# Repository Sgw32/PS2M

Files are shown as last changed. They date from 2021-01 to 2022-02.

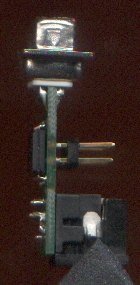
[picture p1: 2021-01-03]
original/ps2mhiiri627_files/hiir07sivusta.jpg

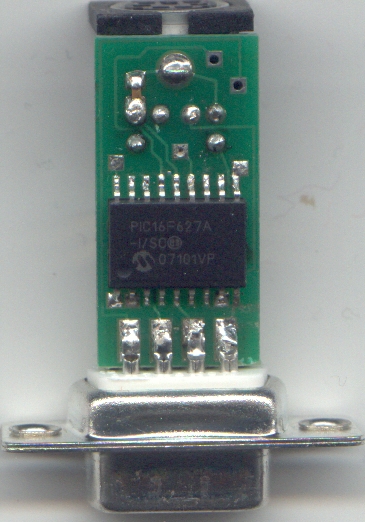
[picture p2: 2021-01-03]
original/ps2mhiiri627_files/hiir07alta.jpg

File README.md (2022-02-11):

# PS2M Amiga mouse adapter

** NEW: ATARI VERSION 

Connect your good old laser PS/2 mouse to your Amiga Retro computer with this cheap and reliable adapter(and forget about non-usable old Amiga mouse)

Features: 

1) PS2M firmware with doubled pins for super reliability of PIC MCU

2) Can be edited to work with Atari

3) Plug&play solution

4) Works with all known Amiga author has

Good resolution, high precision.

Truly 100% open source solution, all hw and sw files available. 

Firmware by Denis Sotchenko's PS2M mouse adapter

PCB by mkl211015 (a little bit adopted to modern PCB software by me)

Flashing using TL866 programmer(see source code)

License:

GNU GPL Version 2 (see gpl.txt)

Original information: http://www.mklboards.fi/ps2mhiiri627/

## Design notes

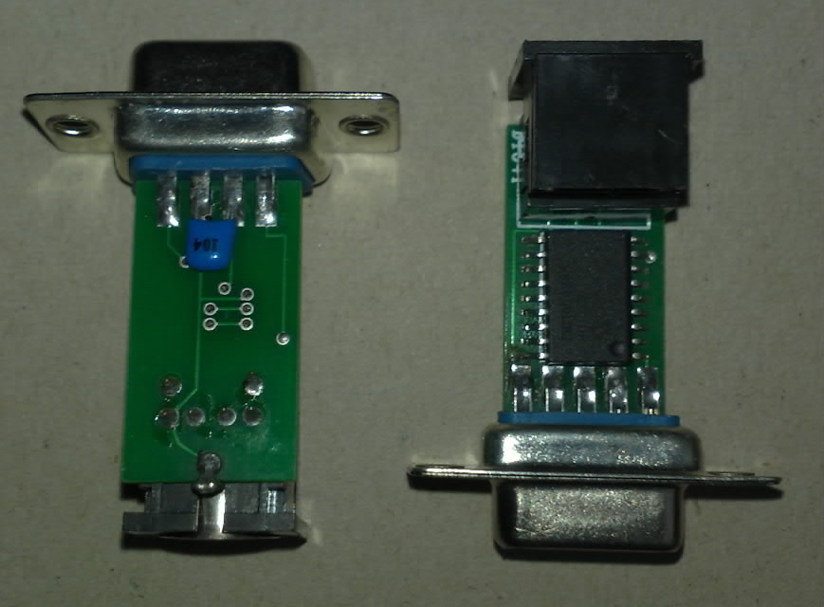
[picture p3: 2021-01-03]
original/ps2mhiiri627_files/hiir08.jpg

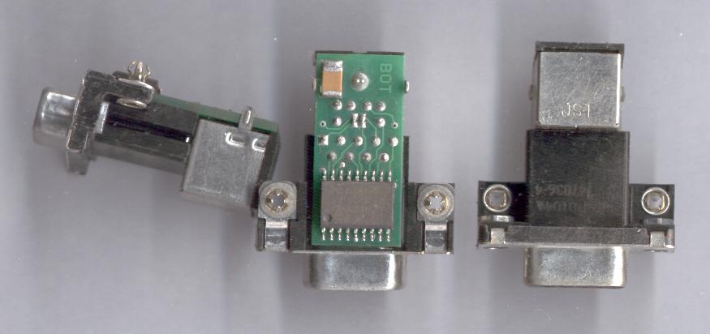
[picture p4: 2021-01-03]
original/ps2mhiiri627_files/hiir21.jpg

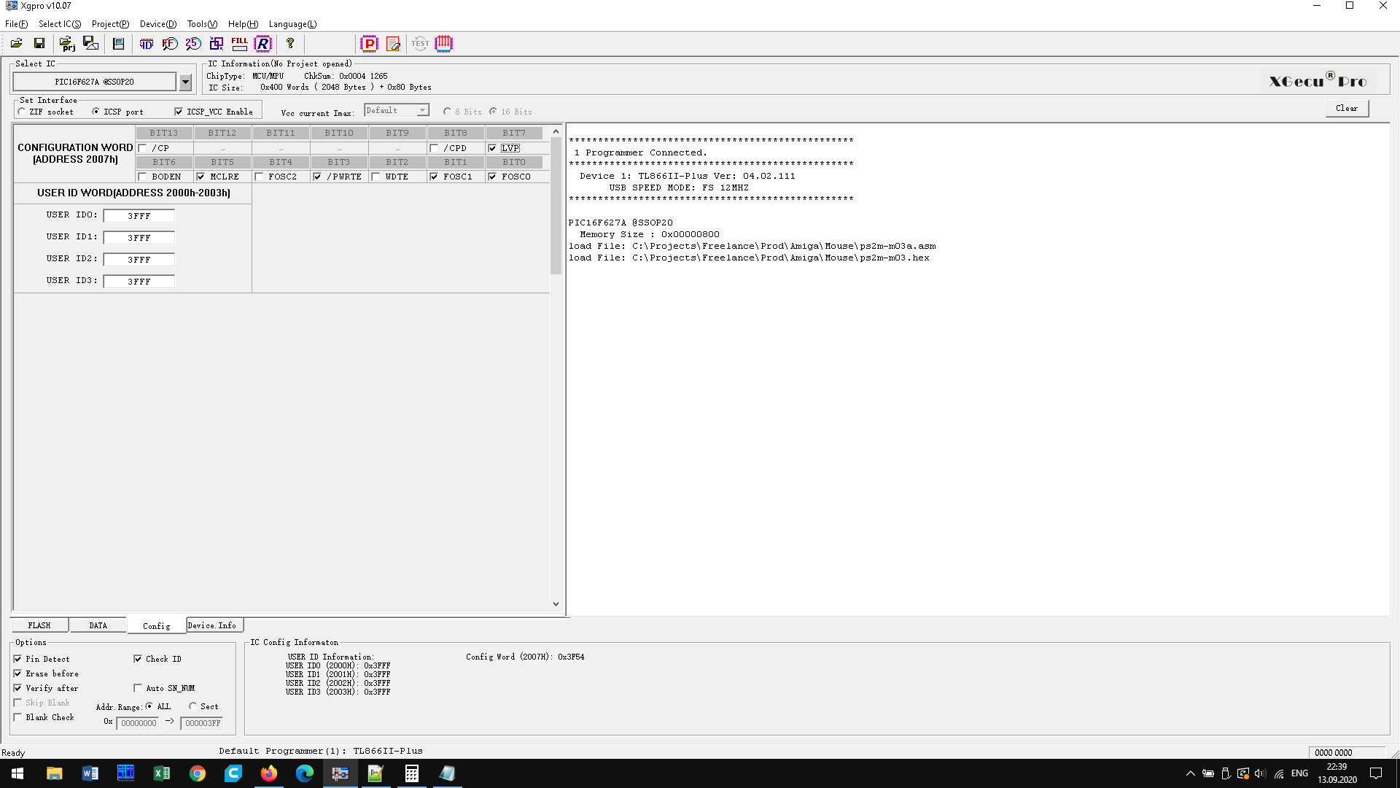
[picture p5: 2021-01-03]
gpasm_ps2m_atari/ps2m_fuse.png

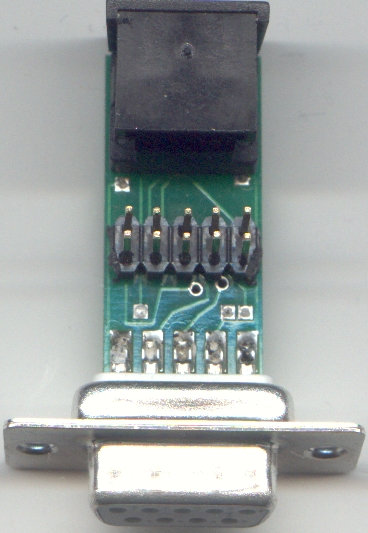
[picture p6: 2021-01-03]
original/ps2mhiiri627_files/hiir07.jpg

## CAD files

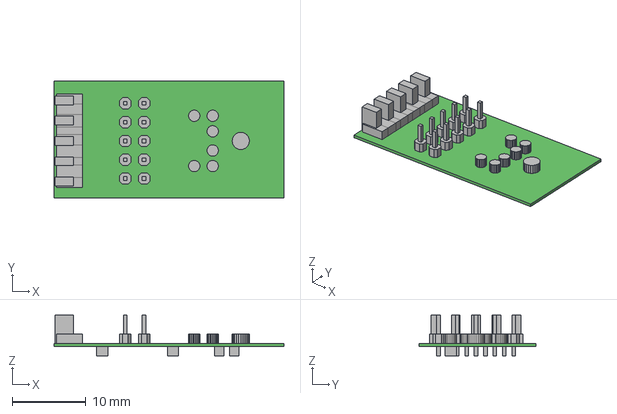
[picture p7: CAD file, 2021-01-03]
hiiri627v07.step
31.1 x 15.9 x 5.49 mm
Extruded x 61

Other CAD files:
hiiri627v07.DWG
hiiri627v07.DXF

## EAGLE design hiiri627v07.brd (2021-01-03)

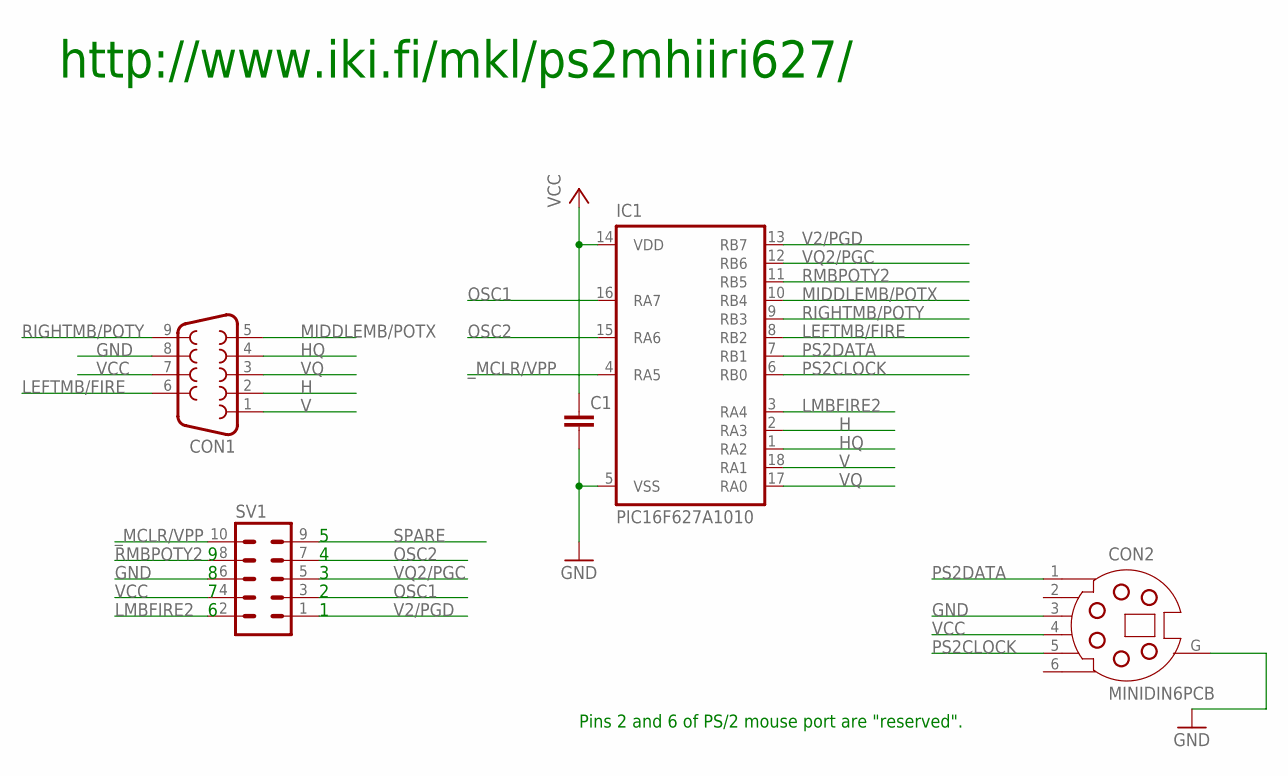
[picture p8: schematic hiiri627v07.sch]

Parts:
C1: C-EUC0805K; C0805K
CON1: F09D
CON2: MINIDIN6PCB
IC1: PIC16F627A1010; SO18-10101020
SV1: ML10

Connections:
GND: C1.2, CON1.8, CON2.3, CON2.G, IC1.5 (VSS), SV1.6
H: CON1.2, IC1.2 (RA3)
HQ: CON1.4, IC1.1 (RA2)
LEFTMB/FIRE: CON1.6, IC1.8 (RB2)
LMBFIRE2: IC1.3 (RA4), SV1.2
MIDDLEMB/POTX: CON1.5, IC1.10 (RB4)
OSC1: IC1.16 (RA7), SV1.3
OSC2: IC1.15 (RA6), SV1.7
PS2CLOCK: CON2.5, IC1.6 (RB0)
PS2DATA: CON2.1, IC1.7 (RB1)
RIGHTMB/POTY: CON1.9, IC1.9 (RB3)
RMBPOTY2: IC1.11 (RB5), SV1.8
SPARE: SV1.9
V: CON1.1, IC1.18 (RA1)
V2/PGD: IC1.13 (RB7), SV1.1
VCC: C1.1, CON1.7, CON2.4, IC1.14 (VDD), SV1.4
VQ: CON1.3, IC1.17 (RA0)
VQ2/PGC: IC1.12 (RB6), SV1.5
_MCLR/VPP: IC1.4 (RA5), SV1.10

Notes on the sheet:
Pins 2 and 6 of PS/2 mouse port are "reserved".
http://www.iki.fi/mkl/ps2mhiiri627/

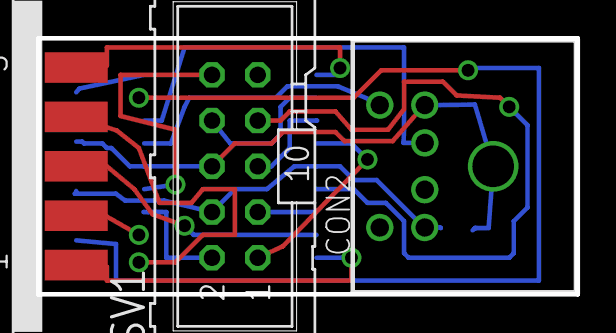
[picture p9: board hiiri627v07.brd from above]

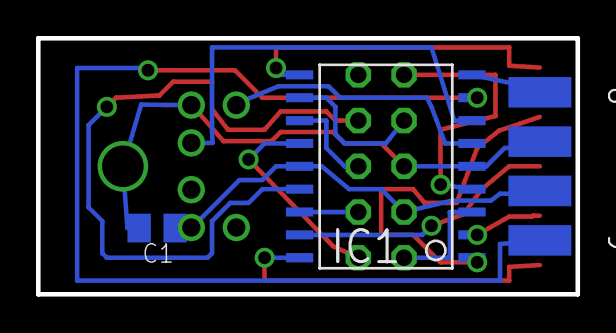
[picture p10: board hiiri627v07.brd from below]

Board: 2 copper layers, 30.0 x 14.2 mm, 5 parts (2 on the bottom side), 18 nets.

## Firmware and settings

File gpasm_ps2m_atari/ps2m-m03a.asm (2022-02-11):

;; mkl modifications to original "ps2m" v1.5 code
;; VER: 1.5.03 (20.03.08) ;http://www.iki.f/mkl/ps2mhiiri627/
;; Rev.A 21.03.08, only comments added, .hex file not changed
;;
;; ps2m functionality "POWER" removed for (my) reading clarity.
;; The mouse "POWER" switching feature was in some older version
;; circuits of mouse adapter, as described in ps2m docs.
;;
;; Copy the output to amiga right mouse button signal line
;; from RB3 also to RA6 and RA7, so connected together they
;; can sink more current. One A1200 didn't recognise right
;; mouse button press, because the voltage remained too high
;; at around 0.3V. Now I can measure 0.16V with one A500+ board.
;; BUT: Please note, that the middle mouse button is not boosted,
;; and it similar POTentiometer input to right mouse button input,
;; so if you have a three button mouse, the middle button may not
;; be recognised as pressed by some Amigas. The POT inputs can
;; give out about 20 mA of current, maybe even leading to destruction
;; of the PIC, because its output will be overloaded.
;; if BOOSTRMB != 0, the feature will be compiled in to the code.
;;
;; I bought a dozen of PIC16LF87 SO-18 chips.
;; if PIC16F87_STUFF != 0, initialize a PIC16LF87 to 4 MHz int. osc.


; $VER: 1.5 (08.07.01)
; COPYRIGHT (C) 2001 RDC SOFTWARE
; Distributed under GPL license - see gpl.txt

; This is a part of ps2m package,
; you can obtain latest version at Aminet:

; ftp://ftp.wustl.edu/pub/aminet/hard/hack/ps2m.lha
; ftp://ftp.wustl.edu/pub/aminet/hard/hack/ps2m.readme

; Use picasm by Timo Rossi to compile.
; Amiga version of picasm is included in devpic package:

; ftp://ftp.wustl.edu/pub/aminet/dev/cross/devpic.lha
; ftp://ftp.wustl.edu/pub/aminet/dev/cross/devpic.readme

; For any questions: rdc@cyberlan.mtu-net.ru

; PORTA0 - VQ
; PORTA1 - V
; PORTA2 - HQ
; PORTA3 - H
; PORTA4 - LMB (not/used)

; Swap V and HQ - atari version
; PORTA1 and PORTA2

; PORTB0 - PS2CLOCK (n/u)
; PORTB1 - PS2DATA (n/u)
; PORTB2 - LEFTMB
; PORTB3 - RIGHTMB
; PORTB4 - MIDDLEMB
; PORTB5 - RMBPOTY2 (n/u)
; PORTB6 - VQ2/PGC (n/u)
; PORTB7 - V2/PGD (n/u)



	device	pic16f876
	include "16f876.i"
	include	"macros.i"


SPEED	equ	46

BOOSTRMB equ 123 ;;Use it
;;Add current sinking capability to the right mouse button pressed
;;signal line towards Amiga (D9 pin 9). It is not a normal TTL-input.
;;Pins 16 (RA7) and 15 (RA6) of 18-pin PIC with internal oscillator need
;;to be connected together with RB3 (PIC pin 9, D9-connector pin 9)
;;PortB3 outputs Right mouse button to Amiga
;;PortA6 and A7, trisb bits 6 and 7


PIC16F87_STUFF equ 123;; for some PIC16LF87 chips I got.

; ---------
; variables
; ---------

	org	0x20

memstart
count		ds	1
recvb		ds	1
recvc		ds	1
recvd		ds	2
recvdt		ds	1
sendata		ds	1
sendetc		ds	1
intw		ds	1
ints		ds	1
wdtp		ds	1
wdtm		ds	2
temp1		ds	1
currbyte	ds	1
xdif		ds	1
ydif		ds	1
xdir		ds	1
ydir		ds	1
xspeed		ds	2
yspeed		ds	2
xcount		ds	1
ycount		ds	1
xtemp		ds	1
ytemp		ds	1
flags		ds	1
extflags	ds	1

byte1		ds	1
byte2		ds	1
byte3		ds	1
byte4		ds	1
zdif		ds	1
zcount		ds	1

q0		ds	1
q1		ds	1
q2		ds	1
q3		ds	1
q4		ds	1

mem_end		org	0x000

; ---------------
; bit definitions
; ---------------

fpkt1	equ	0
fpkt2	equ	1
fpkt3	equ	2
fbyte	equ	3
fnores	equ	4
fnofps	equ	5
fon	equ	6
fwheel	equ	7

ext200	equ	0
extime	equ	1	;ms "intellimouse explorer"
extnso	equ	2	;genius "netscroll optical"
extnof	equ	3
;;	if	POWER-1
extbut	equ	4
;;	endif

; ----------------
; init PIC & mouse
; ----------------
;;reset vectors to address 0x0
start	clrf	INTCON
        movlw   b'00000001'
        option
	goto	start_a

; -----------------
; interrupt handler
; -----------------
;;interrupt vectors to address 0x4
int	local
	bcf	INTCON,1
	movwf	intw
	swapfw	STATUS
	movwf	ints
	bcf	recvd+1,2
	btfsc	PORTB,1
	bsf	recvd+1,2
	rrf	recvd+1
	rrf	recvd
	bsf	wdtp,5		;clear packet bit shift watchdog
	loop	=a,recvc
	movlf	11,recvc
	bsf	flags,fbyte
	movff	recvd,recvdt
=a	swapfw	ints
	movwf	STATUS
	swapf	intw
	swapfw	intw
	retfie
	endlocal

; ----------------------------
; init PIC & mouse - continued
; ----------------------------

start_a	local
	if PIC16F87_STUFF
	;;Switch internal oscillator of LF87 to 4 MHZ
	;;See PIC16F87 datasheet for details about OSCCON (8Fh)
	bcf     STATUS,RP1
	bsf     STATUS,RP0 ;switch to bank 1 (0x80..0xff)
	movlw   b'01100000' ;4 MHz
	movwf   0x0f ;with bank1 = 0x8f
	;;you could monitor IOFS bit for freq stabilizes
	;;but maybe that is not needed, so let's go without doing it
        movlw 0x00
        movwf 0x1B; 0x9B ANSEL on F88 only. (Are using F87)
	;;disable PIC16F87 analog comparators (CMCON)
        movlw   b'00000111'
	movwf   0x1c ;with bank1 = 0x9c
	bcf     STATUS,RP0; go back to bank 0
	endif
	movlf	0xff,0x1f
	clrf	PORTA ;The contents of register PORTA are cleared and the Z bit is set
	clrf	PORTB ;The contents of register PORTB are cleared and the Z bit is set
	movlw	b'11111111'
	tris	PORTA
	tris	PORTB
	endlocal

; clear RAM

	movlf	memstart,FSR
	sublw	mem_end
clearam	clrf	INDF
	incf	FSR
	addlw	0xff
	bnz	clearam
	movlf	TRISB+0x80,FSR ;;INDF is now TRISB

; init variables

	movlf	24,wdtm
	movlf	11,recvc

; delay before turn mouse on

	local
	callw	delayms,0

; wait for mouse

	bcf	INDF,0		;inhibit I/O
	bsf	INDF,1
	callw	delayms,50
	callw	send,0xE8
	callw	send,3
	callw	send,0xE6
	callw	send,0xE6
	callw	send,0xE6
	callw	send,0xE9
	call	bwait		;receive status byte
	call	bwait		;receive resolution (value ignored)
	movwf	temp1		;0x33
	call	bwait		;receive reports per second
	sublw	0x55
	bnz	=ms
	cmplf	0x33,temp1
	bnz	=ms
	bsf	extflags,extnso
	goto	=wheel
=ms	call	testms		;i.m.explorer compatible?
	bz	=h		;yes
	sublw	1		;intellimouse compatible?
	bnz	=i		;no
	bsf	extflags,ext200
	call	testms		;i.m.explorer compatible?
	skipnz
=h	bsf	extflags,extime	;i.m.explorer compatible
=wheel	bsf	flags,fwheel	;intellimouse compatible
=i	callw	send,0xe8	;set resolution
	callw	send,3		;8/mm
	callw	send,0xe6	;scaling 1:1
	callw	send,0xf3	;set 200fps
	callw	send,200
	callw	send,0xf4	;enable mouse in streaming mode
	call	cpoff
	endlocal

; -----------
; check mouse
; -----------

m_check	callw	send,0xE9
	bc	start		;no response? init mouse again
	sublw	0xFA		;ACK?
	bnz	start		;no ACK - init mouse again...
	call	bwait		;receive status byte
	bc	start
	andlw	b'01100000'	;leave only stream & enable flags
	sublw	b'00100000'	;must be stream and enabled
	bnz	start
	btfsc	flags,fnores
	goto	p_init
	call	bwait		;receive resolution (value ignored)
	bc	nores		;no resolution...
	btfsc	flags,fnofps
	goto	p_init
	call	bwait		;receive reports per second
	bc	nofps		;no fps
	goto	p_init

; no resolution & fps report

nores	bsf	flags,fnores
nofps	bsf	flags,fnofps

; ---------------------
; sync serial port init
; ---------------------
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

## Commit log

2021-01-03 PS2M initial commit
    [hiiri627v07.DWG, hiiri627v07.DXF, hiiri627v07.PcbDoc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]
2022-02-11 Big one board + PS2M for Atari + PS2M for tssop pic
    [hiiri627v07.PcbDoc, hiiri627v07.PrjPcb, hiiri627v07.SchDoc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]
